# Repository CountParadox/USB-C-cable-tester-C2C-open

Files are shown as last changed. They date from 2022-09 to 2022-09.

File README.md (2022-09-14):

# USB C cable tester - C2C caberQU
Can my cable support USB 2.0/3.0/3.1/3.2, power delivery? Is a wire broken?



### Preorder one from Kickstarter 
### https://www.kickstarter.com/projects/electr/c2c-caberqu-usb-c-cable-tester

Tindie link: https://www.tindie.com/products/petl/usb-c-cable-tester-c2c-caberqu/

#### What is it?

The C2C caberQU board applies a voltage to all pins of a cable and measures which ones are connected to the other end. It features LEDs for each of the 24 pins and even shield. So in total 25 LEDs offer all possible combinations for USB-C receptacle pin usage in different modes:

- USB 2.0/1.1
- USB Power Delivery
- USB 3.0/3.1/3.2
- Alternate Mode
- Debug Accessory Mode
- Audio Adapter Accessory Mode

See [Wikipedia](https://en.wikipedia.org/wiki/USB-C#USB-C_receptacle_pin_usage_in_different_modes) to check which pin should be connected to where. 



#### Why did you make it?

The amount of possible USB C cable combinations is endless. If you use the wrong cable, data transmission may be slower than possible or certain devices may not work at all. In the USB C standard, the cable plays an important role and has to advertise itself as such. All of them need to have certain pins connected, some need to be grounded, some need to have resistors attached. 

#### What makes it special?

Unfortunately there is no easy way to extract whether a certain cable can support a certain use case. If a cable has a broken pin, that makes it even worse, due to their unpredictable behavior. The C2C caberQU cable tester solves this once and for all. By flipping the USB connectors, the opposing LEDs for some pins light up due to them not being mirrored. That's on purpose and defined in the USB C standard. The product is sold with one CR2032, the PCB and some basic instructions. The USB C cable is not included. You have to extract the needed pins for your desired usage on your own, unfortunately that can not be done universally for all possible combinations.

No dedicated power supply is needed, all necessary power is supplied via the CR2032 battery.

Please note that if you have a cheaper shipping option I'm gladly using it and refunding you the difference. The item still is a prototype. It is working as intended, but funny quirks and other things are possible. It is not certified and only suited for prototyping. 

If you have any questions, just shoot me a message!

#### What makes this one open? 

The full board and production files are provided, you can edit in kicad, get it mass produced, whatever you want.
Massive thanks to Hank for making this possible with his insane skills in kicad!

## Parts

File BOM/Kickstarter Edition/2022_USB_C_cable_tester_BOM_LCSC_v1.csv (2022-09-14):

LCSC Part Number | Manufacturer | Manufacture Part Number | Description | Package | Quoted Manufacturer | Quoted LCSC Part Number | Quantity | Unit Price | Order Price | Quantity Available | Min\Mult Order Qty | RoHS | Part Match Confidence
C964833 | MYOUNG | MY-2032-12 | Battery button CR2032 SMD Battery Connectors ROHS | SMD | MYOUNG | C964833 | 2 | 0.1051 | 0.21 | 6060 | 5\5 | yes | 100%
C713511 | CCTC | TCC0805X5R105M250FT | 25V 1uF X5R ±20% 0805 Multilayer Ceramic Capacitors MLCC - SMD/SMT ROHS | 0805 | CCTC | C713511 | 1 | 0.0065 | 0.01 | 88800 | 50\50 | yes | 100%
C779458 | TUOZHAN | TZ-P2-0805YTCS2-0.8T | 20mA 200mcd 2.4V 595nm Colorless transparence -40℃~+80℃ 590nm~595nm yellow 120° 60mW 0805 Light Emitting Diodes (LED) ROHS | 0805 | TUOZHAN | C779458 | 25 | 0.0096 | 0.24 | 20800 | 50\50 | yes | 100%
C381478 | XUNPU | TYC-324G | 5A USB 3.1 1 260℃ Surface Mount 24 Female -45℃~+85℃ Type-C SMD,7.9x8.94x3.16mm USB Connectors ROHS | SMD,7.9x8.94x3.16mm | XUNPU | C381478 | 2 | 0.5825 | 1.17 | 3108 | 1\1 | yes | 100%
C2907294 | FOJAN | FRC0805J101 TS | ±5% 125mW Thick Film Resistors 150V ±100ppm/℃ -55℃~+155℃ 100Ω 0805 Chip Resistor - Surface Mount ROHS | 0805 | FOJAN | C2907294 | 25 | 0.0016 | 0.04 | 52200 | 100\100 | yes | 100%

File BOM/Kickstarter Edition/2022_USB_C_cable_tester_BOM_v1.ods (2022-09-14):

Name | Value | Layout | Package
USB C cable tester
CR2032 holder |  | G1 | CR2032-HOLDER-C964833
MLC Cap | 1u | C1 | C0805
LED | yellow | LED1 LED2 LED3 LED4 LED5 LED6 LED7 LED8 LED9 LED10 LED11 LED12 LED13 LED14 LED15 LED16 LED17 LED18 LED19 LED20 LED21 LED22 LED23 LED24 LED25 | CHIPLED_0805
Resistor | 100 | R1 R2 R3 R4 R5 R6 R7 R8 R9 R10 R11 R12 R13 R14 R15 R16 R17 R18 R19 R20 R21 R22 R23 R24 R25 | R0805
USB C |  | J3 J4
CR2032 |  | CR2032 lithium battery
PCB |  | Manufactured PCB

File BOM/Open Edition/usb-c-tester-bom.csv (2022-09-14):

Comment | Designator | Footprint | LCSC
1uF | C1 | Capacitor_SMD:C_0805_2012Metric | C28323
BAT-HLD-001-TR | G1 | BAT_BAT-HLD-001-TR | C964833
105450-0101 | J1,J2 | usb-c-tester:105450-0101 | C134092
LED | LED1,LED2,LED3,LED4,LED5,LED6,LED7,LED8,LED9,LED10,LED11,LED12,LED13,LED14,LED15,LED16,LED17,LED18,LED19,LED20,LED21,LED22,LED23,LED24,LED25 | LED_SMD:LED_0603_1608Metric | C72038
100 | R1,R2,R3,R4,R5,R6,R7,R8,R9,R10,R11,R12,R13,R14,R15,R16,R17,R18,R19,R20,R21,R22,R23,R24,R25 | Resistor_SMD:R_0603_1608Metric | C22775

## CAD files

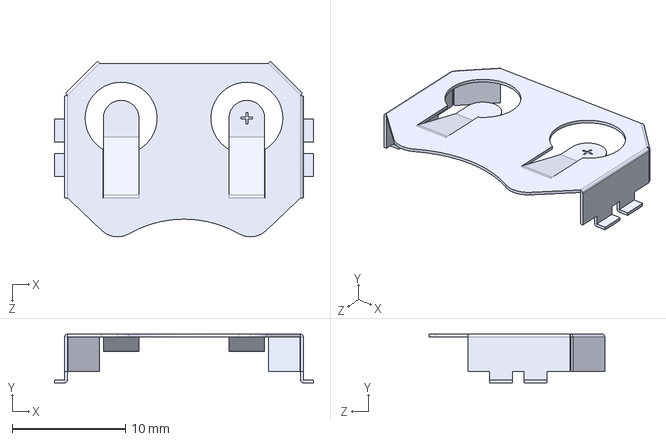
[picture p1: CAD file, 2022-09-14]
BAT-HLD-001-TR.step
22.9 x 4.32 x 15.5 mm

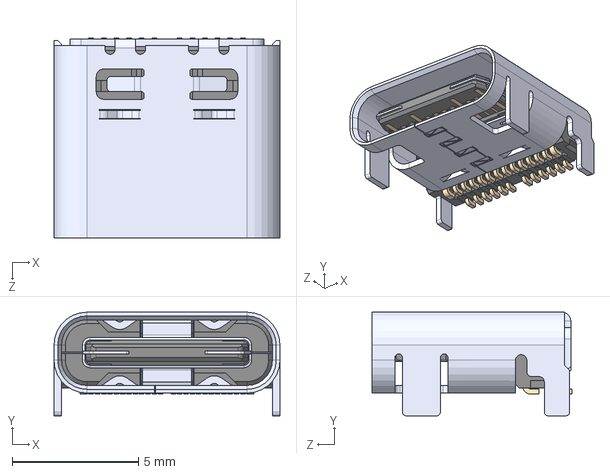
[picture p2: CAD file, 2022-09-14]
105450-0101.step
8.94 x 4.10 x 7.90 mm

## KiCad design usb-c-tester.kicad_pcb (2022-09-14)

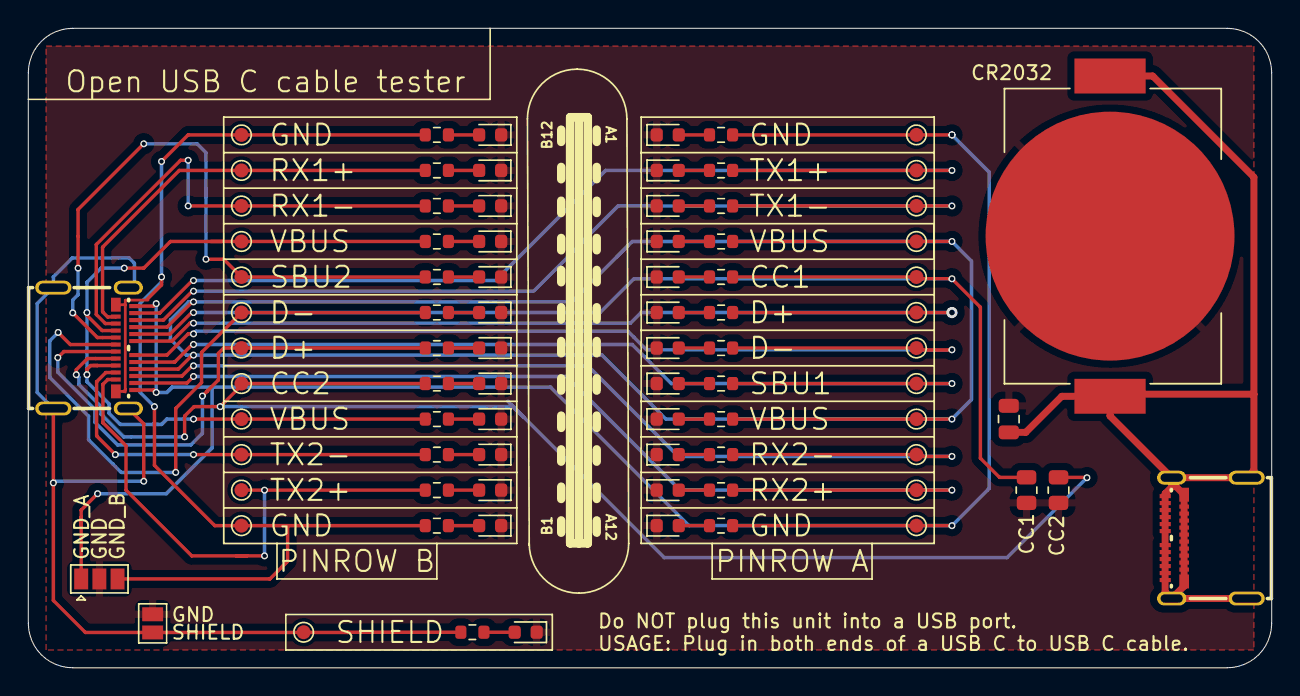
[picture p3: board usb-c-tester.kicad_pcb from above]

Board: 2 copper layers, 88.9 x 45.7 mm, 83 parts (0 on the bottom side), 48 nets.

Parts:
C1: 1uF; C_0805_2012Metric
G1: BAT-HLD-001-TR; BAT_BAT-HLD-001-TR
J1, J2: 105450-0101
JP1: SolderJumper_3_Open; SolderJumper-3_P1.3mm_Open_Pad1.0x1.5mm
JP2: SolderJumper_2_Open; SolderJumper-2_P1.3mm_Open_Pad1.0x1.5mm
LED1, LED2, LED3, LED4, LED5, LED6, LED7, LED8, LED9, LED10, LED11, LED12, LED13, LED14, LED15, LED16, LED17, LED18, LED19, LED20, LED21, LED22, LED23, LED24, LED25: LED; LED_0603_1608Metric
R1, R2, R3, R4, R5, R6, R7, R8, R9, R10, R11, R12, R13, R14, R15, R16, R17, R18, R19, R20, R21, R22, R23, R24, R25: 100; R_0603_1608Metric
R26, R27: R; R_0805_2012Metric
TP1, TP2, TP3, TP4, TP5, TP6, TP7, TP8, TP9, TP10, TP11, TP12, TP13, TP14, TP15, TP16, TP17, TP18, TP19, TP20, TP21, TP22, TP23, TP24, TP25: TestPoint; TestPoint_Pad_D1.0mm

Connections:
CC1: J2.A5, R5.1, R26.1, TP5.1
CC2: J2.B5, R16.1, R27.1, TP16.1
D1+: J2.A6, R6.1, TP6.1
D1-: J2.A7, R7.1, TP7.1
D2+: J2.B6, R17.1, TP17.1
D2-: J2.B7, R18.1, TP18.1
GND: C1.2, G1.N1, JP1.2, JP2.2, LED1.1, LED2.1, LED3.1, LED4.1, LED5.1, LED6.1, LED7.1, LED8.1, LED9.1, LED10.1, LED11.1, LED12.1, LED13.1, LED14.1, LED15.1, LED16.1, LED17.1, LED18.1, LED19.1, LED20.1, LED21.1, LED22.1, LED23.1, LED24.1, LED25.1, R26.2, R27.2
GND_A: J2.A1, J2.A12, JP1.1, R1.1, R23.1, TP1.1, TP23.1
GND_B: J2.B1, J2.B12, JP1.3, R12.1, R24.1, TP12.1, TP24.1
unnamed: LED1.2, R1.2
unnamed: LED2.2, R2.2
unnamed: LED3.2, R3.2
unnamed: LED4.2, R4.2
unnamed: LED5.2, R5.2
unnamed: LED6.2, R6.2
unnamed: LED7.2, R7.2
unnamed: LED8.2, R8.2
unnamed: LED9.2, R9.2
unnamed: LED10.2, R10.2
unnamed: LED11.2, R11.2
unnamed: LED12.2, R12.2
unnamed: LED13.2, R13.2
unnamed: LED14.2, R14.2
unnamed: LED15.2, R15.2
unnamed: LED16.2, R16.2
unnamed: LED17.2, R17.2
unnamed: LED18.2, R18.2
unnamed: LED19.2, R19.2
unnamed: LED20.2, R20.2
unnamed: LED21.2, R21.2
unnamed: LED22.2, R22.2
unnamed: LED23.2, R23.2
unnamed: LED24.2, R24.2
unnamed: LED25.2, R25.2
RX1+: J2.B11, R21.1, TP21.1
RX1-: J2.B10, R20.1, TP20.1
RX2+: J2.A11, R10.1, TP10.1
RX2-: J2.A10, R9.1, TP9.1
SBU1: J2.A8, R8.1, TP8.1
SBU2: J2.B8, R19.1, TP19.1
SHIELD: J2.S1, J2.S2, J2.S3, J2.S4, JP2.1, R11.1, TP11.1
TX1+: J2.A2, R2.1, TP2.1
TX1-: J2.A3, R3.1, TP3.1
TX2+: J2.B2, R13.1, TP13.1
TX2-: J2.B3, R14.1, TP14.1
VBUS_A: J2.A4, J2.A9, R4.1, R22.1, TP4.1, TP22.1
VBUS_B: J2.B4, J2.B9, R15.1, R25.1, TP15.1, TP25.1
VCC: C1.1, G1.P1, G1.P2, J1.A1, J1.A2, J1.A3, J1.A4, J1.A5, J1.A6, J1.A7, J1.A8, J1.A9, J1.A10, J1.A11, J1.A12, J1.B1, J1.B2, J1.B3, J1.B4, J1.B5, J1.B6, J1.B7, J1.B8, J1.B9, J1.B10, J1.B11, J1.B12, J1.S1, J1.S2, J1.S3, J1.S4

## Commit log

2022-09-14 Complete kicad files with cpl and bom for jlcpcb
2022-09-14 Open files added
    [2022_USB_C_cable_tester_BOM_LCSC_v1.csv, 2022_USB_C_cable_tester_BOM_v1.ods]
2022-09-14 Open USB C Tester files added
    [105450-0101.step, 2022_USB_C_cable_tester_BOM_LCSC_v1.csv, 2022_USB_C_cable_tester_BOM_v1.ods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]
